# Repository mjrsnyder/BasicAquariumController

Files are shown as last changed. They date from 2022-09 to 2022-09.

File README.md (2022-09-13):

# BasicAquariumController

### Goals
* Monitor and report tempurature
* Monitor and report tank water level
* Monitor and report top-off water level
* Control 12v fan for cooling
* Control 12v pump for top-off and maybe water changes
* Control lights using an IR transmitter
* Use as many on-hand components as possible
* Avoid controlling mains power
* Inexpensive
* Expandable via i2c
* Controllable with HomeAssistant but also have built failsafes in case HA is unavailable

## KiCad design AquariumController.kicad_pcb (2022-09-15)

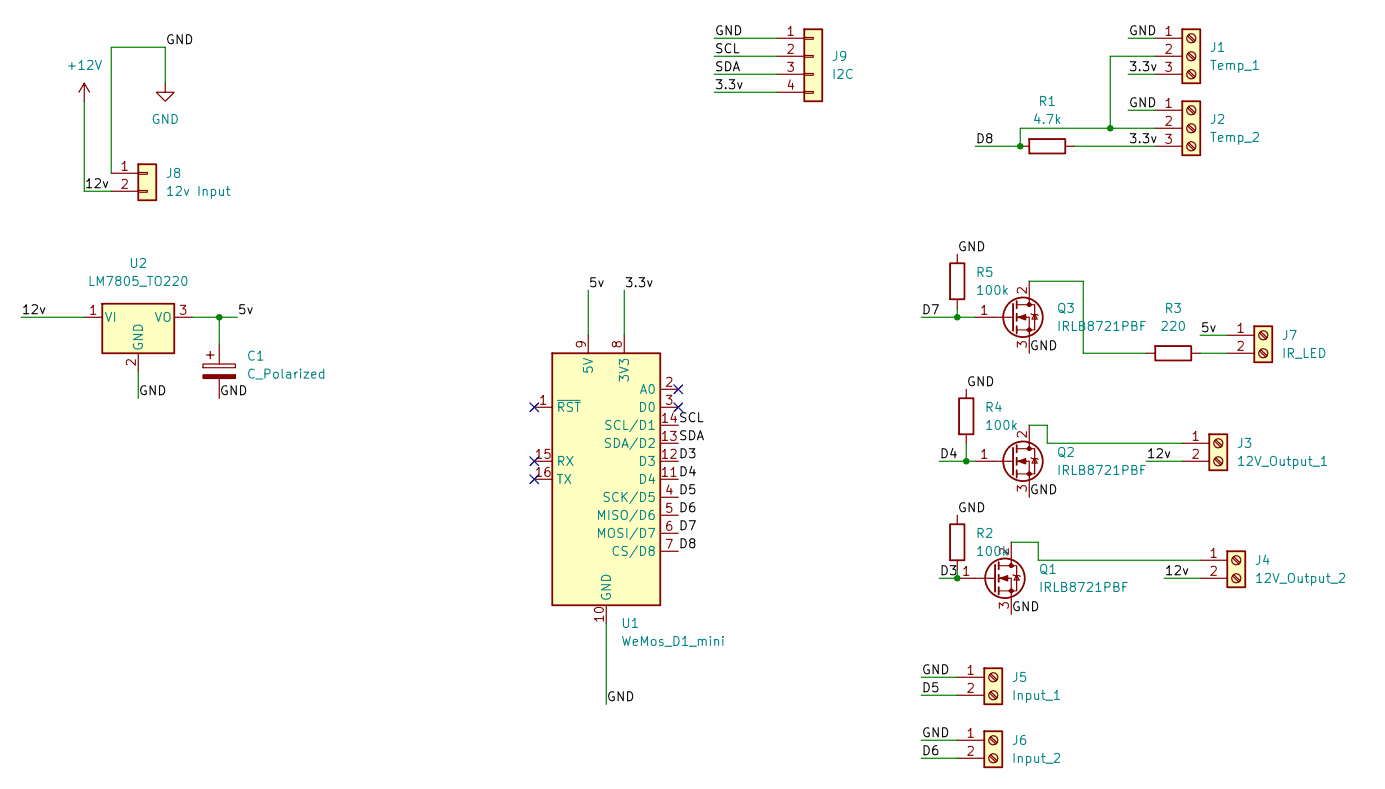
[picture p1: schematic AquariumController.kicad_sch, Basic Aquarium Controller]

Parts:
C1: C_Polarized; C_Radial_D5.0mm_H11.0mm_P2.00mm
J1: Temp_1; TerminalBlock_Phoenix_MKDS-1,5-3-5.08_1x03_P5.08mm_Horizont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
J2: Temp_2; TerminalBlock_Phoenix_MKDS-1,5-3-5.08_1x03_P5.08mm_Horizont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
J3: 12V_Output_1; TerminalBlock_Phoenix_MKDS-1,5-2-5.08_1x02_P5.08mm_Horizont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
J4: 12V_Output_2; TerminalBlock_Phoenix_MKDS-1,5-2-5.08_1x02_P5.08mm_Horizont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
J5: Input_1; TerminalBlock_Phoenix_MKDS-1,5-2-5.08_1x02_P5.08mm_Horizont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
J6: Input_2; TerminalBlock_Phoenix_MKDS-1,5-2-5.08_1x02_P5.08mm_Horizont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
J7: IR_LED; TerminalBlock_Phoenix_MKDS-1,5-2-5.08_1x02_P5.08mm_Horizont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
J8: 12v Input; JST_XH_B2B-XH-A_1x02_P2.50mm_Vertical
J9: I2C; JST_XH_S4B-XH-A_1x04_P2.50mm_Horizontal
Q1, Q2, Q3: IRLB8721PBF; TO-220-3_Vertical
R1: 4.7k; R_Axial_DIN0207_L6.3mm_D2.5mm_P10.16mm_Horizontal
R2, R4, R5: 100k; R_Axial_DIN0207_L6.3mm_D2.5mm_P10.16mm_Horizontal
R3: 220; R_Axial_DIN0207_L6.3mm_D2.5mm_P10.16mm_Horizontal
U1: WeMos_D1_mini; WEMOS_D1_mini_light
U2: LM7805_TO220; TO-220-3_Vertical

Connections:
+12V: J3.2, J4.2, J8.2, U2.1 (VI)
/3.3v: J1.3, J2.3, J9.4, R1.1, U1.8 (3V3)
/5v: C1.1, J7.1, U1.9 (5V), U2.3 (VO)
/D3: Q1.1 (G), R2.2, U1.12 (D3)
/D4: Q2.1 (G), R4.2, U1.11 (D4)
/D5: J5.2, U1.4 (SCK/D5)
/D6: J6.2, U1.5 (MISO/D6)
/D7: Q3.1 (G), R5.2, U1.6 (MOSI/D7)
/D8: J1.2, J2.2, R1.2, U1.7 (CS/D8)
/SCL: J9.2, U1.14 (SCL/D1)
/SDA: J9.3, U1.13 (SDA/D2)
GND: C1.2, J1.1, J2.1, J5.1, J6.1, J8.1, J9.1, Q1.3 (S), Q2.3 (S), Q3.3 (S), R2.1, R4.1, R5.1, U1.10 (GND), U2.2 (GND)
unnamed: J3.1, Q2.2 (D)
unnamed: J4.1, Q1.2 (D)
unnamed: J7.2, R3.1
unnamed: Q3.2 (D), R3.2

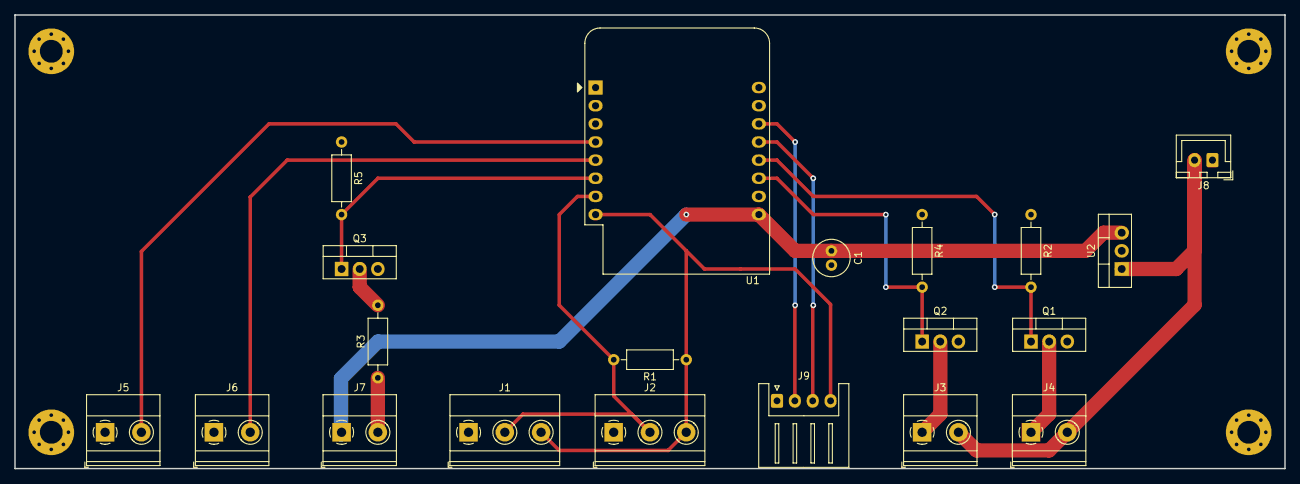
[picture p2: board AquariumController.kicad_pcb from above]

Board: 2 copper layers, 177.8 x 63.5 mm, 20 parts (0 on the bottom side), 16 nets.

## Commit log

2022-09-14 Swap out all the mosfets/bjts add the i2c breakout flip the power to the right side
    [AquariumController.kicad_pcb, AquariumController.kicad_sch]
2022-09-15 make the holes not on the schematic and fix the name of the 12v input
    [AquariumController.kicad_pcb, AquariumController.kicad_sch]
